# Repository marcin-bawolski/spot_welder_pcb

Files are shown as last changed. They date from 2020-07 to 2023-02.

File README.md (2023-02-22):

# spot_welder_pcb
PCB for STM8S based timer to control spot welder in KiCAD format.

Board using STM8s module and four digit 7-seg LED display as timer in 999 ms range.
Used as timer for spot-welding by triggering triac and large transformer.

uses sch and cb libraries from https://github.com/marcin-bawolski/kicad-libs.git

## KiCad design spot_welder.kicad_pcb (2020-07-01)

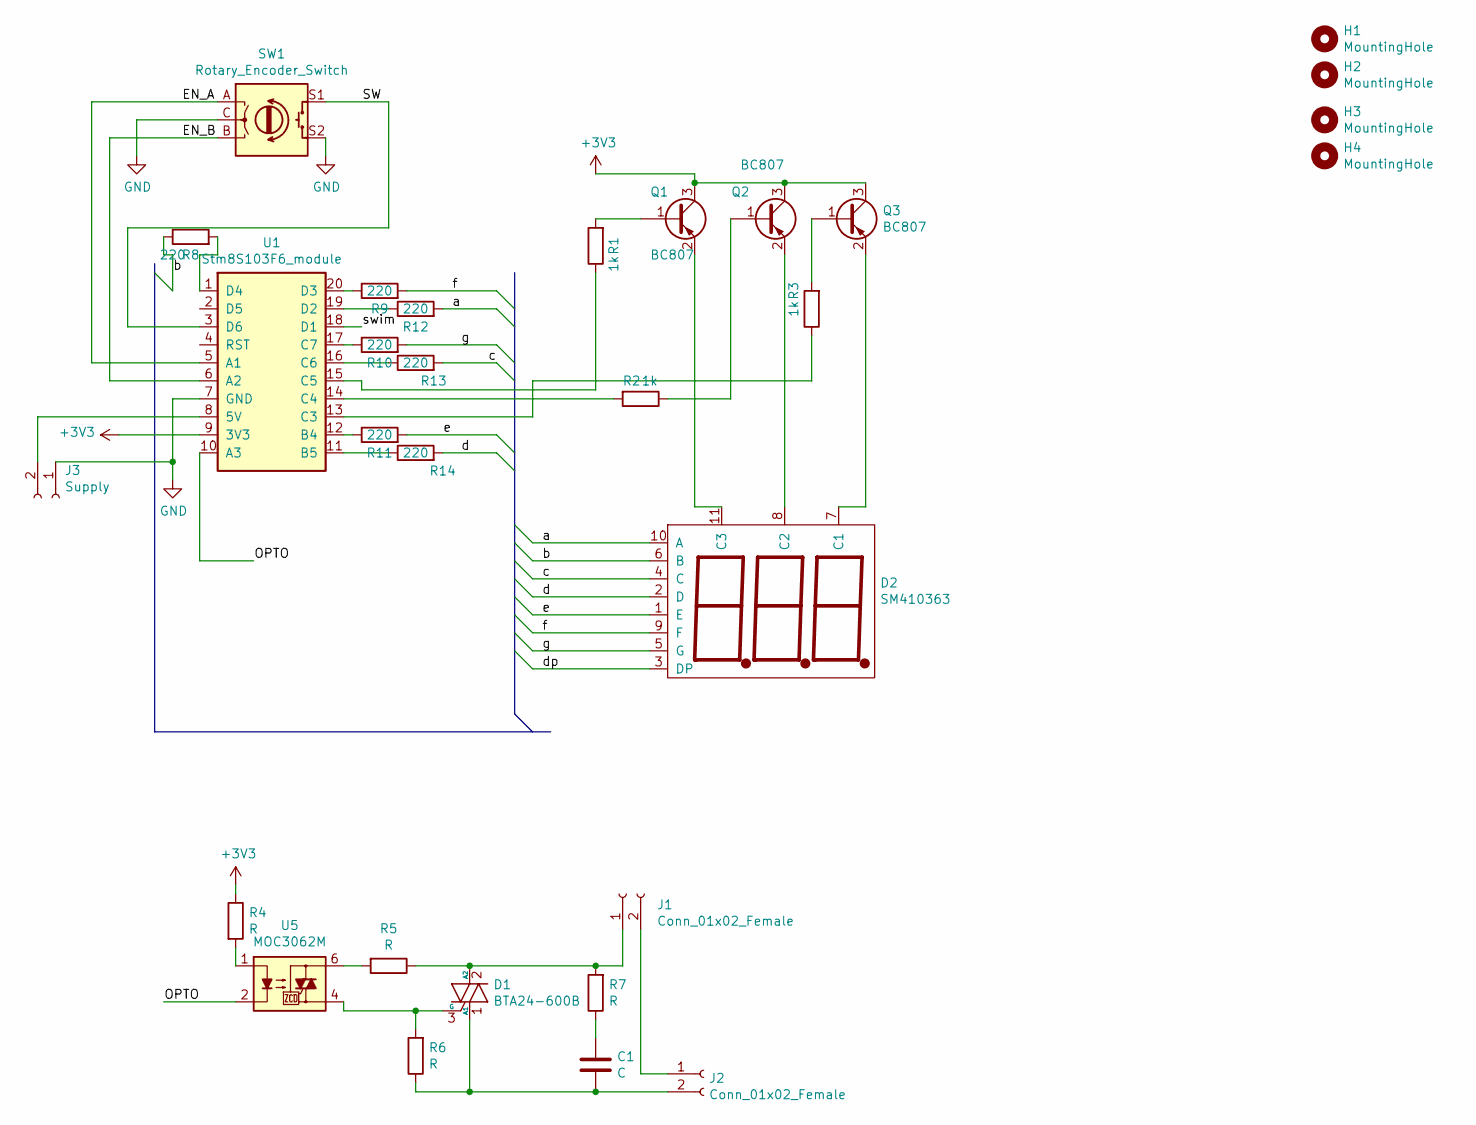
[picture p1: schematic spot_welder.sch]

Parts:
C1: C; C_Rect_L13.0mm_W3.0mm_P10.00mm_FKS3_FKP3_MKS4
D1: BTA24-600B; TO-220-3_Vertical
D2: SM410363
H1, H2, H3, H4: MountingHole; MountingHole_3.2mm_M3_DIN965_Pad
J1, J2: Conn_01x02_Female; PhoenixContact_GMSTBVA_2,5_2-G-7,62_1x02_P7.62mm_Vertical
J3: Supply; PhoenixContact_GMSTBVA_2,5_2-G-7,62_1x02_P7.62mm_Vertical
Q1, Q2, Q3: BC807; SOT-23
R1, R2, R3: 1k; R_0805_2012Metric_Pad1.15x1.40mm_HandSolder
R4: R; R_0805_2012Metric
R5, R6, R7: R; R_Axial_DIN0207_L6.3mm_D2.5mm_P10.16mm_Horizontal
R8, R9, R10, R11, R12, R13, R14: 220; R_0805_2012Metric_Pad1.15x1.40mm_HandSolder
SW1: Rotary_Encoder_Switch; RotaryEncoder_Alps_EC12E-Switch_Vertical_H20mm_CircularMoun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
U1: Stm8S103F6_module; DIP-20_600_ELL
U5: MOC3062M; DIP-6_W7.62mm_LongPads

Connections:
+3V3: Q1.3 (C), Q2.3 (C), Q3.3 (C), R4.1, U1.9 (3V3)
/EN_A: SW1.A, U1.5 (A1)
/EN_B: SW1.B, U1.6 (A2)
/OPTO: U1.10 (A3), U5.2
/SW: SW1.S1, U1.3 (D6)
/a: D2.10 (A), R12.2
/b: D2.6 (B), R8.1
/c: D2.4 (C), R13.2
/d: D2.2 (D), R14.2
/dp: D2.3 (DP)
/e: D2.1 (E), R11.2
/f: D2.9 (F), R9.2
/g: D2.5 (G), R10.2
/swim: U1.18 (D1)
GND: J3.1, SW1.C, SW1.S2, U1.7 (GND)
unnamed: C1.1, R7.1
unnamed: C1.2, D1.1 (A1), J2.2, R6.1
unnamed: D1.2 (A2), J1.1, R5.1, R7.2
unnamed: D1.3 (G), R6.2, U5.4
unnamed: D2.7 (C1), Q3.2 (E)
unnamed: D2.8 (C2), Q2.2 (E)
unnamed: D2.11 (C3), Q1.2 (E)
unnamed: J1.2, J2.1
unnamed: J3.2, U1.8 (5V)
unnamed: Q1.1 (B), R1.2
unnamed: Q2.1 (B), R2.1
unnamed: Q3.1 (B), R3.2
unnamed: R1.1, U1.15 (C5)
unnamed: R2.2, U1.14 (C4)
unnamed: R3.1, U1.13 (C3)
unnamed: R4.2, U5.1
unnamed: R5.2, U5.6
unnamed: R8.2, U1.1 (D4)
unnamed: R9.1, U1.20 (D3)
unnamed: R10.1, U1.17 (C7)
unnamed: R11.1, U1.12 (B4)
unnamed: R12.1, U1.19 (D2)
unnamed: R13.1, U1.16 (C6)
unnamed: R14.1, U1.11 (B5)

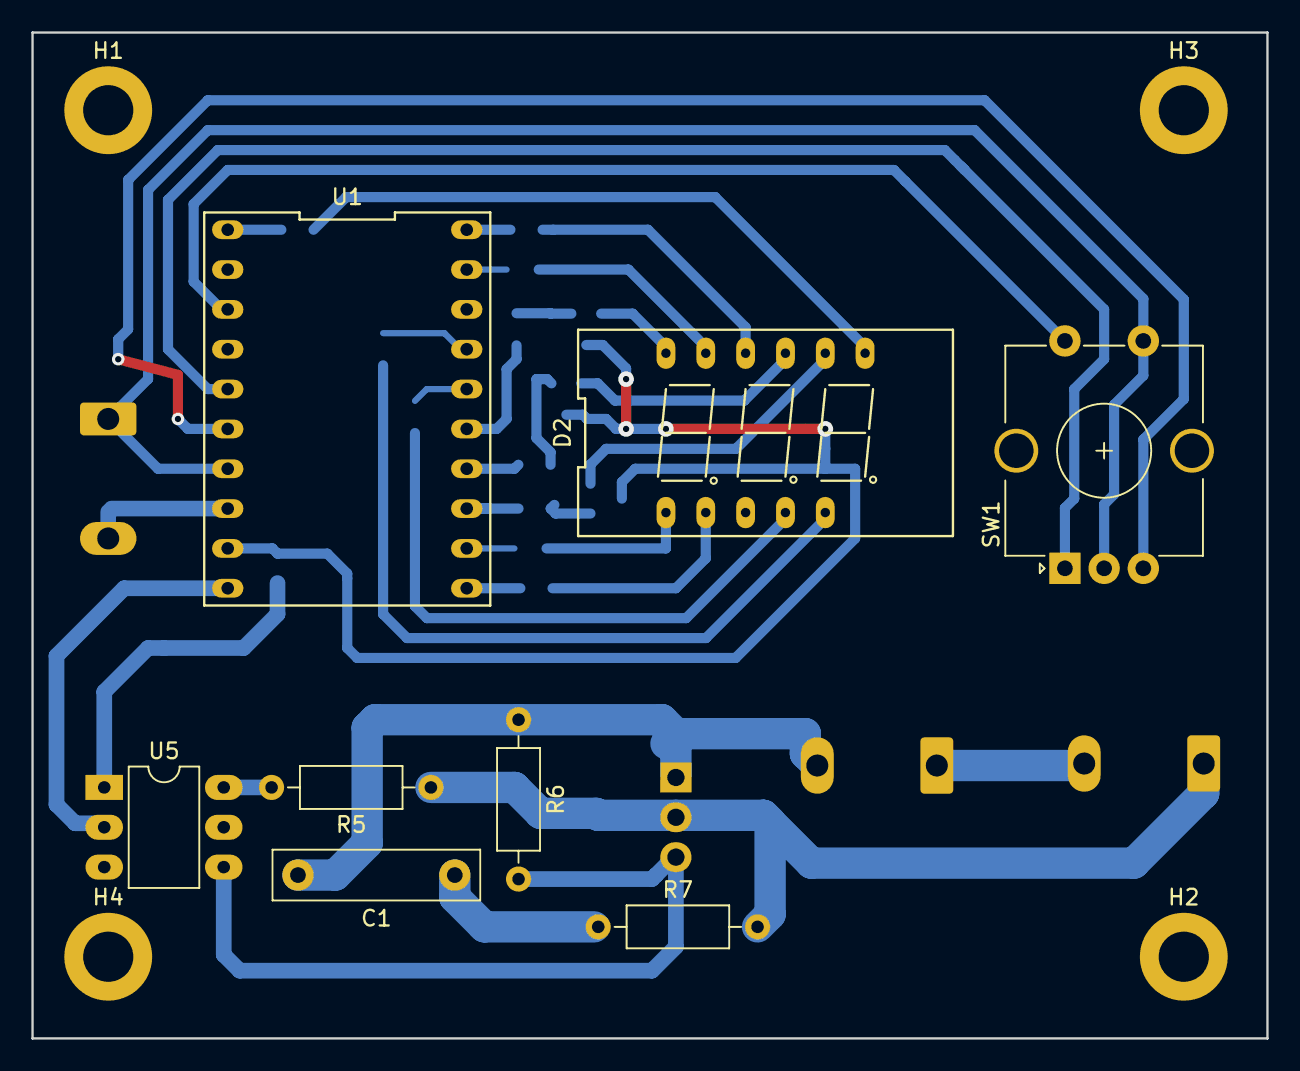
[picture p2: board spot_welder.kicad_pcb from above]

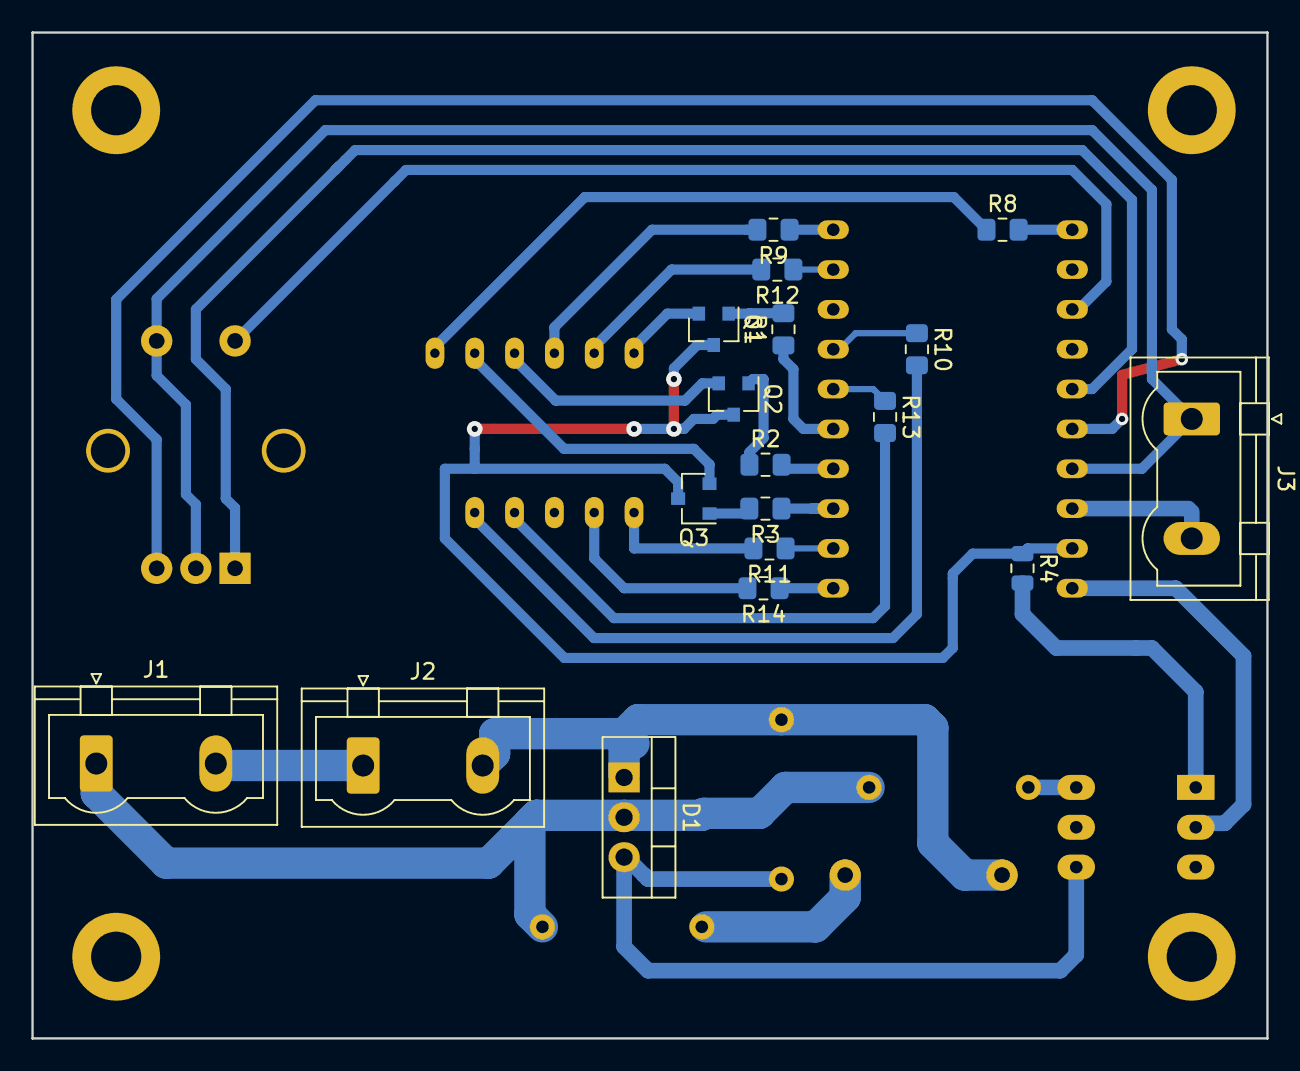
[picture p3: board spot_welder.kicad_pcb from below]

Board: 2 copper layers, 78.7 x 64.1 mm, 30 parts (18 on the bottom side), 37 nets.

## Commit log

2020-06-19 Swapped display of 100 and 1
    [spot_welder.kicad_pcb, spot_welder.sch]
2020-06-19 stm8 module footprint changed
    [spot_welder.sch]
2020-06-19 mounting holes added
    [spot_welder.kicad_pcb, spot_welder.sch]
2020-06-19 Add segment resistors
    [spot_welder.kicad_pcb, spot_welder.sch]
2020-06-19 encoder moved to right of display
    [spot_welder.kicad_pcb]
2020-06-23 3x7seg LED module
    [spot_welder.kicad_pcb, spot_welder.sch]
2020-06-23 HV part at bottom of PCB
    [spot_welder.kicad_pcb]
2020-07-01 clearances increased, vias enlarged
    [spot_welder.kicad_pcb, spot_welder.sch]
2023-02-22 library name updated
    [spot_welder.sch]
